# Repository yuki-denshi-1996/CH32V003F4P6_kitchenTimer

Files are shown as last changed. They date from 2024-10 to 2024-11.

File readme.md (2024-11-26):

<!---
 SPDX-FileCopyrightText: 2024 yuki-denshi-1996 <matsukawa.software@gmail.com>
 SPDX-License-Identifier: BSD 3-Clause
--->
# 目次
- [目次](#目次)
- [はじめに](#はじめに)
- [gitのディレクトリ構成](#gitのディレクトリ構成)
- [基板に使用した部品等](#基板に使用した部品等)
- [標準プログラムでの使い方](#標準プログラムでの使い方)
- [プログラムの変更](#プログラムの変更)
- [仕様](#仕様)
- [ライセンス](#ライセンス)
- [連絡先](#連絡先)

# はじめに
これはCH32V003F4P6でタイマーを作ろうというプロジェクトです。<BR>

# gitのディレクトリ構成
CH32V003F4P6_Timer_2024_Kit ディレクトリにプログラムが入っています。MounRiver Studioにて開発しています。プロジェクトごと読み込んでください。<BR>
timer_V1 ディレクトリに基板データが入っています。KiCad 8.0で設計しています。timer_V1.kicad_pro を読み込んでください。<BR>

# 基板に使用した部品等
ここに出しているものは、あくまでも推奨しているものです。自由に変更していただいて構いません。<BR>
ここに書いているものは、すべて秋月電子通商様で購入できる部品となっています。<BR>
| 部品番号  |  部品名 |  リンク | 備考|
| --- | --- | --- | ---|
| BZ1  |  圧電スピーカー |  https://akizukidenshi.com/catalog/g/g104118/ | |
| C1 | セラミックコンデンサ 0.1uF  | https://akizukidenshi.com/catalog/g/g113582/  |  |
| D1| SBD  | https://akizukidenshi.com/catalog/g/g116384/  |  |
| F1  | リセッタブルヒューズ  |  https://akizukidenshi.com/catalog/g/g101354/ | |
|  J2  | 電源コネクタ (XH-2コネクタ)  |  https://akizukidenshi.com/catalog/g/g112247/ |  |
|  Q1-Q4 | DTA123E (デジタルトランジスタ)  |  https://akizukidenshi.com/catalog/g/g112465/ |  |
| R1-R8, R10 | 抵抗 1kΩ (1/6Wサイズ)  |  https://akizukidenshi.com/catalog/g/g116102/ | |
| SW1-SW6 | タクトスイッチ  | https://akizukidenshi.com/catalog/g/g101282/ |  |
| U2|  E40364-IFOW (時計用7セグメントLED) | https://akizukidenshi.com/catalog/g/g114426/  |  |
| U3  | CH32V003F4P6 (マイコン)  |  https://akizukidenshi.com/catalog/g/g118061/ | |

# 標準プログラムでの使い方
ここでは、プログラムを改変していないことを前提条件として、使い方を記します。<BR>

まず電源を入れます。<BR>

MINスイッチで分数を, SECスイッチで秒数を変更することができます。<BR>
スタート・ストップをする場合には、START/STOPスイッチを押してください。<BR>
クリア(0分0秒に戻す)場合には、MINボタンとSECボタンを同時におしてください。<BR>

次にFASTボタンの説明です。<BR>
このタイマーには時刻を記憶できるボタンが2つ付いています。<BR>
登録したい時間をMIN/SECスイッチで設定したあと、FASTスイッチをピッとなるまで長押しします<BR>
次回以降は、登録した方のボタンを押すだけで、時間がセットされます<BR>
FASTボタンは2つありますので、2つの時間を記憶しておけます。<BR>

最後にストップウォッチモードの説明です。<BR>
0分0秒の状態でSTART/STOPを押すと、ストップウォッチになり、時間がカウントされます。<BR>

なお、動作していない状態(時間を測定していない状態)でしばらく放置しておくと、自動的に消灯し、スリープモードに入ります。<BR>
復帰する場合には、MIN/SEC/START・STOPボタンのいずれかを押してください。<BR>

# プログラムの変更
使用するピンは、圧電スピーカーが接続されているピン(PC5)を除き、自由に変更できます。<BR>
変更する場合は、プログラムソースにあるUser/Timer_2024_Kit.hの宣言を変更してください。<BR>

````diff
//PIN定義
-#define SEG_A PC2
+#define SEG_A PD1
#define SEG_B PC4
#define SEG_C PD3
#define SEG_D PC7
#define SEG_E PC6
#define SEG_F PC3
#define SEG_G PD4
#define SEG_DOT PD2
````

注意：PA1, PA2はプッシュプル出力/(プルアップ・プルダウンを使用しない)入力のみ可能です。基本的には変更しないことをおすすめします。

また、タイマーのビープ音は、Timer_2024_Kit.hのBEEP_FREQで変更できます。使用したい周波数を入れてください。
````diff
//BEEP音の高さ
-#define BEEP_FREQ 2000
+#define BEEP_FREQ 2500 //2500Hzに設定
````
その他、細かい設定もTimer_2024_Kit.hにて変更可能です。

# 仕様
電源は乾電池3本 (1.5V x 3 = 4.5V)を使用することを前提としていますが、USB電源等5Vでも使えます。

# ライセンス
このプログラムにはBSD 3-Clauseライセンスが適用されています。<BR>
詳しくは[3条項BSDライセンス](https://licenses.opensource.jp/BSD-3-Clause/BSD-3-Clause.html)をご覧ください。

# 連絡先
バグや追加機能の実装等はGithubのissueに書き込んでください。<BR>
ライセンス・再配布・その他問い合わせについては、下のメールアドレスまたはGoogle Formからどうぞ。<BR>
<BR>
メールアドレス:matsukawa.software＠gmail.com (アットマークを半角にしてください)<BR>
[Google Form お問い合わせフォーム](https://denshi1996.com/?page_id=68#toc1)<BR>

©️2024 - Yuki (denshi-1996) 以上

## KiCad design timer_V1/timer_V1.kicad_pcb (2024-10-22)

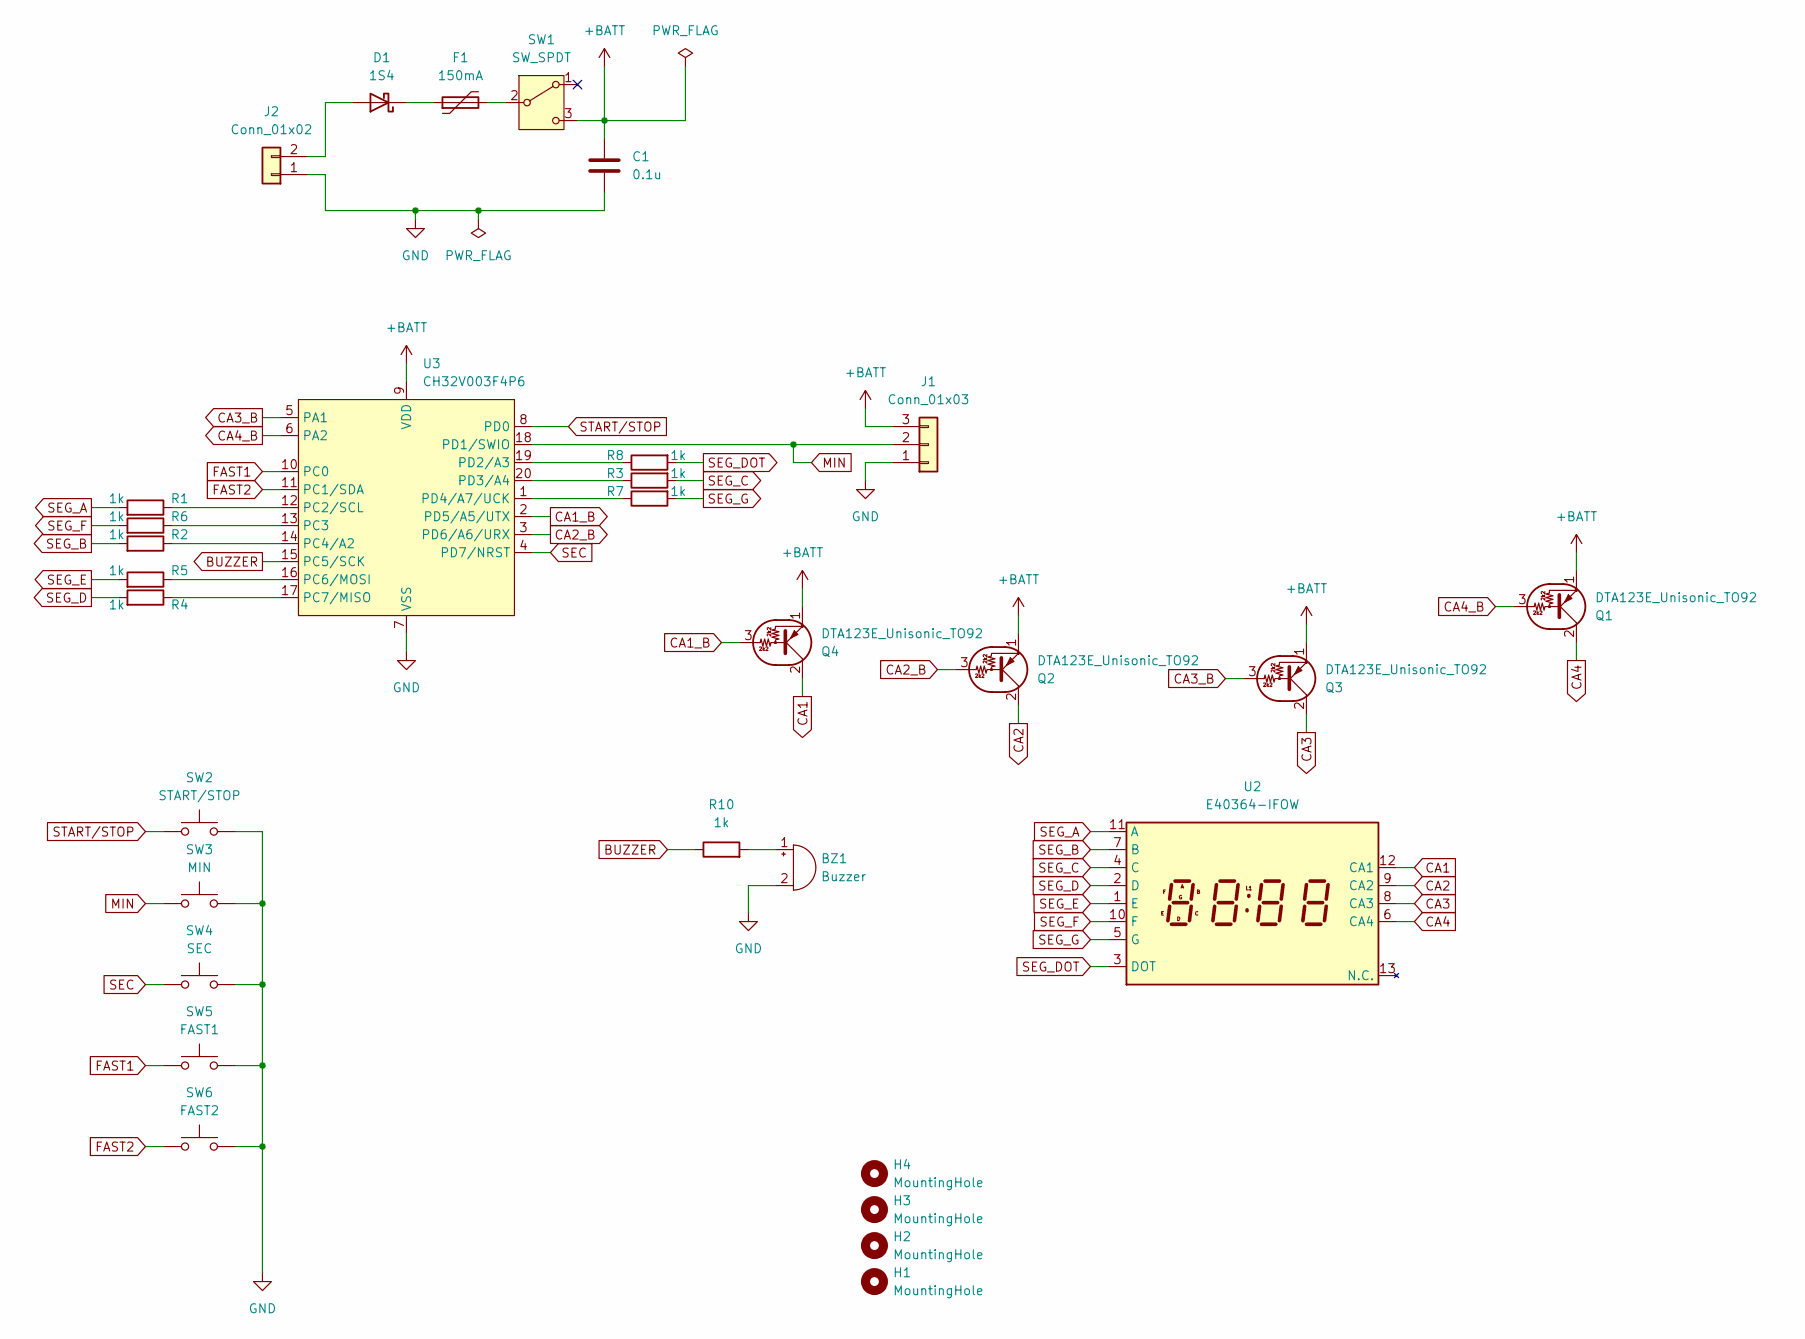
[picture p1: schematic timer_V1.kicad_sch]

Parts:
BZ1: Buzzer; AKI_CERAMIC_BUZZER_PKM13EPYH4000-A0
C1: 0.1u; C_DISK_P5.0mm
D1: 1S4; R_1_4W
F1: 150mA; R_1_6W
H1, H2, H3, H4: MountingHole; PAD_3mm_5mm
J1: Conn_01x03; PinHeader_1x03_Program
J2: Conn_01x02; JST_XH_B2B-XH-A_1x02_P2.50mm_Vertical
Q1, Q2, Q3, Q4: DTA123E_Unisonic_TO92; yuki_TO-92_Wide
R1, R2, R3, R4, R5, R6, R7, R8, R10: 1k; R_1_6W
SW1: SW_SPDT; Yuki_Slide_Switch_P2.54
SW2: START/STOP; SW_PUSH_6mm
SW3: MIN; SW_PUSH_6mm
SW4: SEC; SW_PUSH_6mm
SW5: FAST1; SW_PUSH_6mm
SW6: FAST2; SW_PUSH_6mm
U2: E40364-IFOW; E40364-IFOW_DEKAI
U3: CH32V003F4P6; TSSOP-20_4.4x6.5mm_P0.65mm

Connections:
+BATT: C1.1, J1.3, Q1.1 (E), Q2.1 (E), Q3.1 (E), Q4.1 (E), SW1.3 (C), U3.9 (VDD)
BUZZER: R10.1, U3.15 (PC5/SCK)
CA1: Q4.2 (C), U2.12 (CA1)
CA1_B: Q4.3 (B), U3.2 (PD5/A5/UTX)
CA2: Q2.2 (C), U2.9 (CA2)
CA2_B: Q2.3 (B), U3.3 (PD6/A6/URX)
CA3: Q3.2 (C), U2.8 (CA3)
CA3_B: Q3.3 (B), U3.5 (PA1)
CA4: Q1.2 (C), U2.6 (CA4)
CA4_B: Q1.3 (B), U3.6 (PA2)
FAST1: SW5.1, U3.10 (PC0)
FAST2: SW6.1, U3.11 (PC1/SDA)
GND: BZ1.2 (-), C1.2, J1.1, J2.1, SW2.2, SW3.2, SW4.2, SW5.2, SW6.2, U3.7 (VSS)
MIN: J1.2, SW3.1, U3.18 (PD1/SWIO)
unnamed: BZ1.1 (+), R10.2
unnamed: D1.2 (A), J2.2
unnamed: D1.1 (K), F1.1
unnamed: F1.2, SW1.2 (B)
unnamed: R1.1, U3.12 (PC2/SCL)
unnamed: R6.1, U3.13 (PC3)
unnamed: R2.1, U3.14 (PC4/A2)
unnamed: R5.1, U3.16 (PC6/MOSI)
unnamed: R4.1, U3.17 (PC7/MISO)
unnamed: R8.1, U3.19 (PD2/A3)
unnamed: R3.1, U3.20 (PD3/A4)
unnamed: R7.1, U3.1 (PD4/A7/UCK)
SEC: SW4.1, U3.4 (PD7/NRST)
SEG_A: R1.2, U2.11 (A)
SEG_B: R2.2, U2.7 (B)
SEG_C: R3.2, U2.4 (C)
SEG_D: R4.2, U2.2 (D)
SEG_DOT: R8.2, U2.3 (DOT)
SEG_E: R5.2, U2.1 (E)
SEG_F: R6.2, U2.10 (F)
SEG_G: R7.2, U2.5 (G)
START/STOP: SW2.1, U3.8 (PD0)

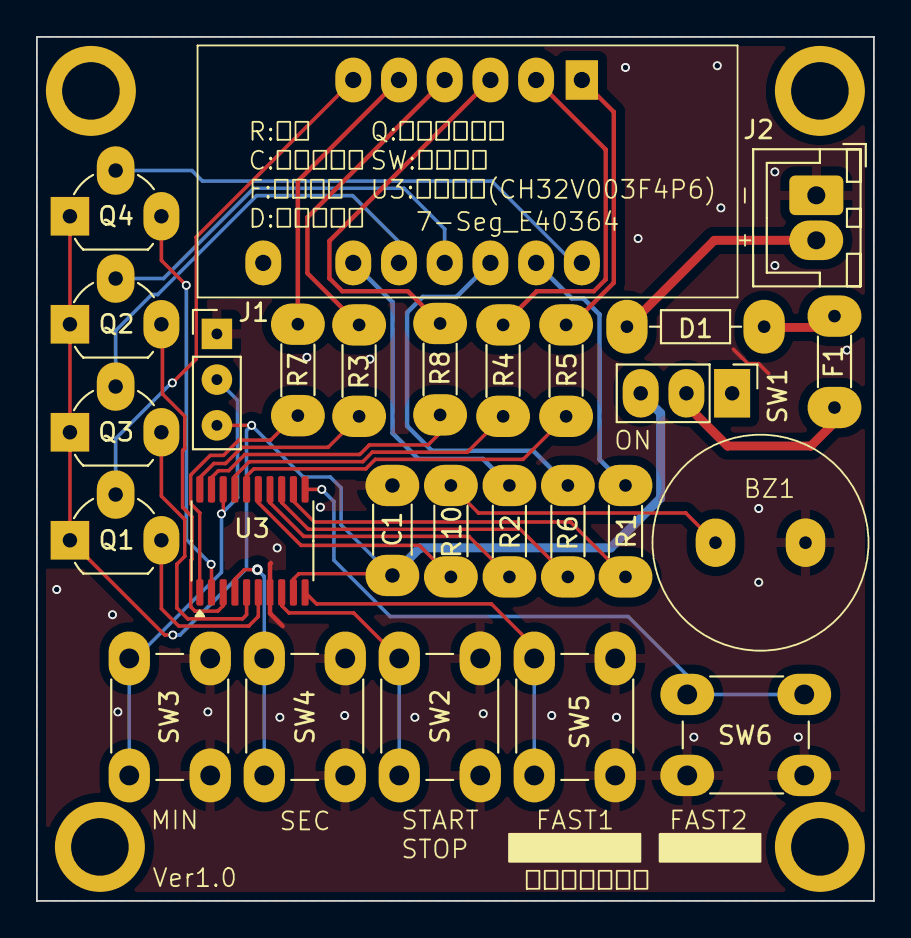
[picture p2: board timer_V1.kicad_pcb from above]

Board: 2 copper layers, 46.5 x 48.0 mm, 31 parts (0 on the bottom side), 36 nets.

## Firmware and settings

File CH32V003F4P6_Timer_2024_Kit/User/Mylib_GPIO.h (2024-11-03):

/*
* SPDX-FileCopyrightText: 2024 yuki-denshi-1996 <matsukawa.software@gmail.com>
* SPDX-License-Identifier: BSD 3-Clause
*/

/*
 * CH32V003F4P6用（CH32V003)GPIO操作ライブラリ
 * Mylib_GPIO.h
 *
 *  Created on: Sep 22, 2024
 *      Author: yuki (denshi-1996)
 */
#include <stdint.h>

#ifndef USER_MYLIB_GPIO_H_
#define USER_MYLIB_GPIO_H_

#define HIGH 1
#define LOW 0

//GPIO定義
#define PA1 0xA1
#define PA2 0xA2

#define PC0 0xC0
#define PC1 0xC1
#define PC2 0xC2
#define PC3 0xC3
#define PC4 0xC4
#define PC5 0xC5
#define PC6 0xC6
#define PC7 0xC7

#define PD0 0xD0
#define PD1 0xD1
#define PD2 0xD2
#define PD3 0xD3
#define PD4 0xD4
#define PD5 0xD5
#define PD6 0xD6
#define PD7 0xD7

//GPIO_MODE
#define INPUT 0b1000
#define F_INPUT 0b1001
#define INPUT_PULLUP 0b1110
#define INPUT_PULLDOWN 0b1010
#define OUTPUT 0b0000
#define OD_OUTPUT 0b0001
#define F_OUTPUT 0b0010
#define F_OD_OUTPUT 0b0011

//GPIO_OUTPUT_SPEED_MODE
#define OUTPUT_SPEED_MODE_10MHz 0b01
#define OUTPUT_SPEED_MODE_2MHz 0b10
#define OUTPUT_SPEED_MODE_50MHz 0b11

//EventGPIO
#define EVENT_RISE 0x01 //Rise(立ち上がり)でイベント発生
#define EVENT_FALL 0x02 //Fall(たち下がり)でイベント発生

//GPIO 初期化（クロック供給）
//GPIOを使う場合は、最初に有効化すること
void GPIOA_init(void);
void GPIOC_init(void);
void GPIOD_init(void);

//AFIO初期化
void AFIO_init(void);

//PINイベント設定関数
//pin:ピン | mode:立ち上がり,たち下がり　どちらか
void eventGPIO(int pin, int mode);

//ピン入出力設定
//pin:ピン番| mode:モード
void pinMode(int pin,int mode);

//ピン出力速度指定関数
//pin:ピン番号|speed_mode:出力スピード設定
int OUTPUT_DEFAULT_SpeedMode(int speed_mode);

//デジタル出力設定
//pin:ピン番号|value:1(HIGH) or 0(LOW)
void digitalWrite(int pin,int value);

//デジタル入力設定
//返り値：Pinの状態|Pin:ピン番号
int digitalRead(int pin);

//bitビット置き換え関数
uint32_t bit_replace(uint32_t data, uint32_t byte, uint8_t len, uint8_t shift);

#endif /* USER_MYLIB_GPIO_H_ */

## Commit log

2024-10-22 [fix] FAST2ボタンが使用できない問題を解決
2024-10-22 [Comment] コメントを追加してわかりやすくしました
2024-11-03 [Add] LICENSEを追加
2024-11-04 [Add] Readme.mdを追加
2024-11-04 [Fix] Readme.mdの変更
